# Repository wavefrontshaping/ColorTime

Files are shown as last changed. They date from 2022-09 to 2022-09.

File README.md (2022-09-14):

Color Time
==========
## *A passive-agressive tool to tell the speaker it is time to stop talking*

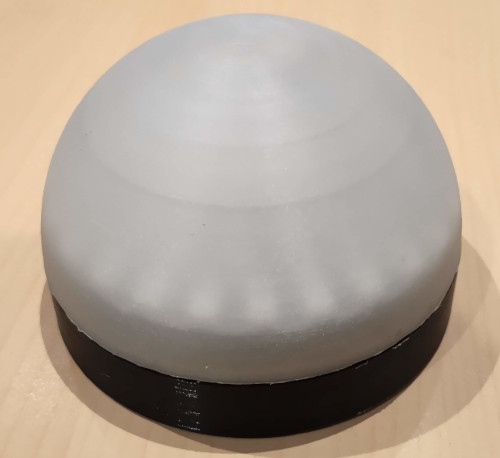
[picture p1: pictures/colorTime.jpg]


## Table of Content
1. [What is it?](#what)
2. [How does it work?](#how)
3. [Build it](#build)
4. [Usage](#usage)
5. [Credits](#credits)

## 1. What is it? 
During scientific talks it is sometimes difficult, or awkward, for the chairmen to warn speakers that they are exceeding their allotted time.
We developed a device, 
designed to be placed between the speaker and the audience, 
that indicates using a color coded light how much time they have left. 
It also signals the time for question and the end of the allotted time with color flashes.

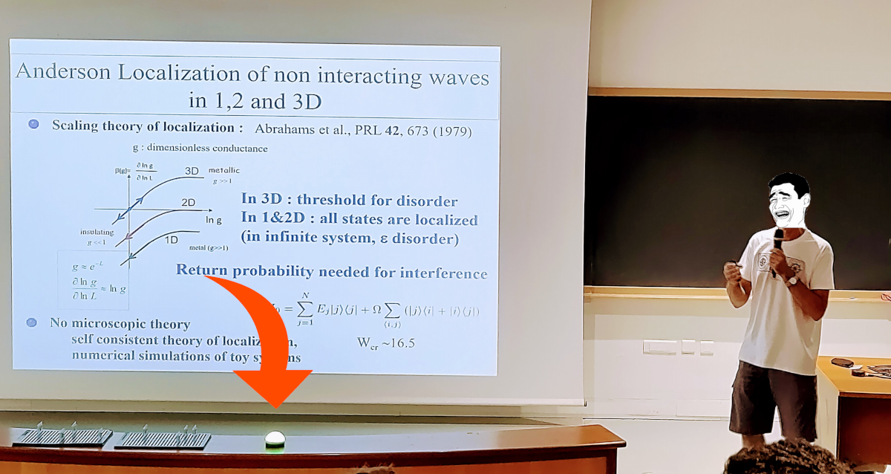
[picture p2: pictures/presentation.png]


## 2. How does it work? 

Once started and set up, the light of the device will gradually change from green to red during the time of the talk. 
It will also signal the time for questions with few red flashes and then will flash blue and red at the end of the talk to tell the speaker and chairman that the time is up. 

The device can be controlled using a push button by directly pressing on the device and/or using bluetooth with a smartphone.

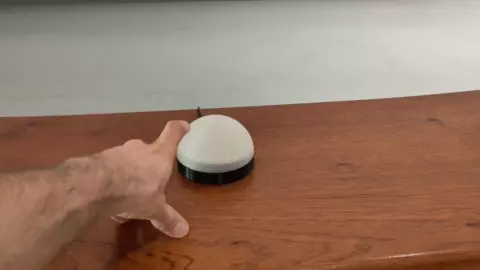
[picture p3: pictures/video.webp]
video


## 3. Build it 
### 3.1 Bill of materials
* 1x Raspberry Pi Pico
* 1. 6x6x4.5mm push button
* 1x 61-LED [[buy](https://www.amazon.fr/gp/product/B07L7ZPPV9/ref=ppx_yo_dt_b_asin_title_o00_s00?ie=UTF8&psc=1)] [[instructions](https://www.make-it.ca/ws2812-neopixel-ring-to-attiny85/)]
* 1x HC-05 (or HC-06) Bluetooth board [Optional]
* White and black (or colored) PLA for 3d printed parts

### 3.2 3d-printed parts

150 micron resolution is good enough. 
For the top part, use can use a translucent plastic but using white is good enough as light will still go through given the thickness of the shell.

### 3.3 Assembly

### 3.4 Button

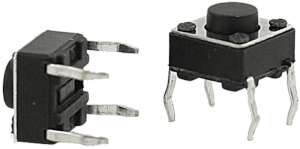
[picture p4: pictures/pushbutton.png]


Solder the two pins of the button, one to a `GND` pin of the board, the other to pin `GP9`.
Be careful to pass the wire through the hole before soldering them the the board.

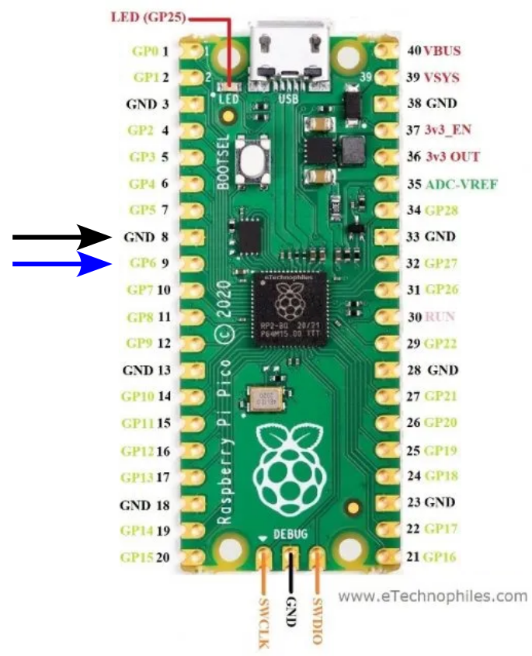
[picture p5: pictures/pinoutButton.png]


Then, push the button into the designated hole. 
Ideally, make it so the button sticks out a little bit. 
This way, you can press directly on the white dome to press the button. 

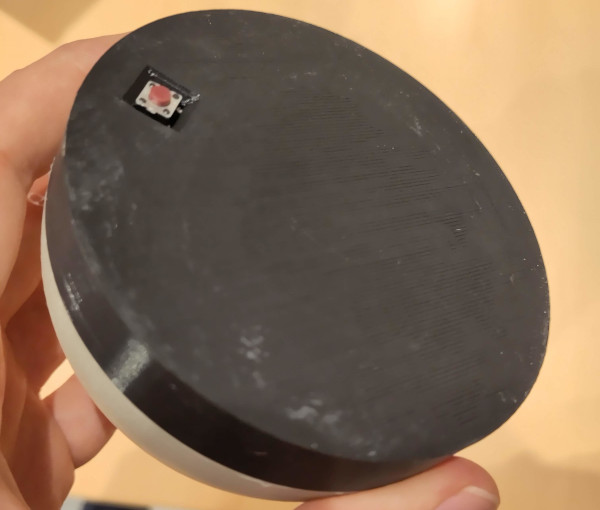
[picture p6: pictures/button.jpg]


### 3.5 LEDs
Simply follow the tutorial [here](https://www.make-it.ca/ws2812-neopixel-ring-to-attiny85/) for soldering the different rings. 
Then solder the `DI` digital input to `GP20`. Use `VBUS` (usb power) for `Vcc` and any `GND` pin for ground.

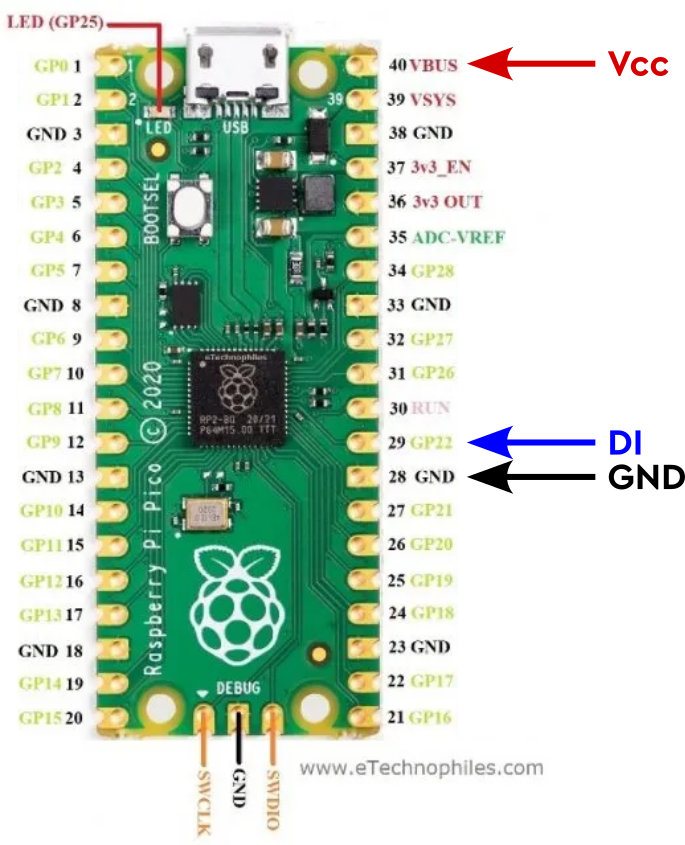
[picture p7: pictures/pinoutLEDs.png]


### 3.6 Blueooth [optional]

Once every thing soldered, place the Pico board so that the 
micro-usb socket is properly in place. 
You should be able to plug a power cord without moving the board.
You can keep the Pico in place with one drop of glue gun in the corners of the board.

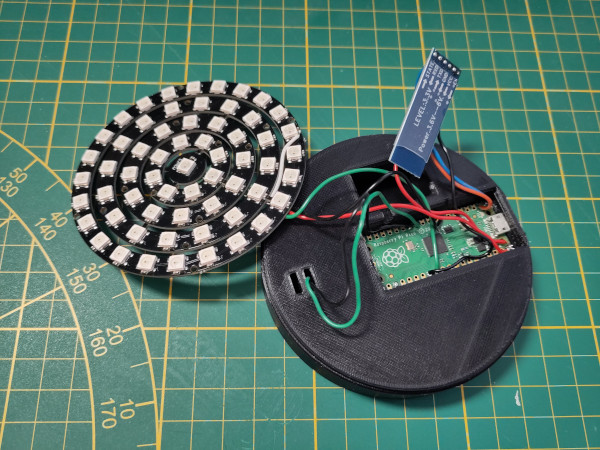
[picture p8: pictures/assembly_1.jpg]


Place a piece of paper (to prevent short circuit) on top of the Pico board and put the HC-05 on top of it.

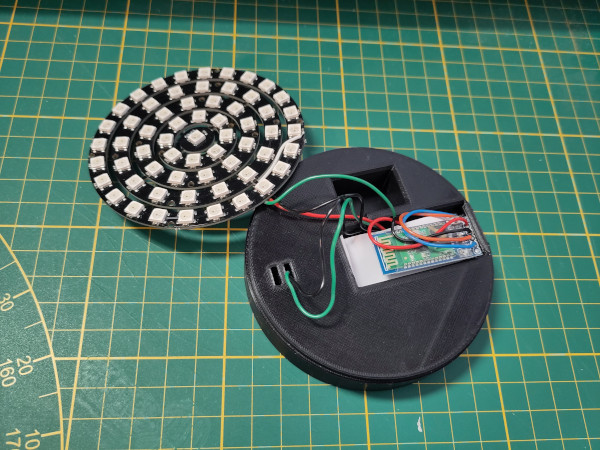
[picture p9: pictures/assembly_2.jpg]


### 3.7 Final assembly

Use a glue gun to keep the LEDs in place and final snap the top white dome onto the base. 
And you are done!

## 4. Usage

### 4.1 Preparation
If you intend to use the device without bluetooth, 
you need to set up few parameters in the code. 
However, you could make it work out of the box with just editing 
`state_time` to fit the duration of the talks.

* `state_time`: the list of different time for talks in minutes. 
  **Do not edit the first one** as it correspond to the demo of a duration of 20 seconds and for which the time for question is modified to be equal to 10 seconde, regardless of the value of `T_QUESTION`
* `state_colors`: list of colors for the different times. 
  Each color should be a list or tuple of three integers between 0 and 255. 
  This list should be of the same length as `state_time`
* `T_QUESTION`: time allotted for question. 
  The device will flash red for 4 seconds `T_QUESTION` minutes before the end of the talk.
* `BRIGHTNESS_MIN`: brightness at the beginning of the countdown.
* `BRIGHTNESS_MAX`:  brightness at the END of the countdown.
* `BRIGHTNESS_FLASH`: brightness for the flashes for the question signal and the end of the talk.
  
### 4.2 Power source

Plug the device to any power source using a micro-USB cable. 
A small power bank is typically enough for hours of usage.

### 4.3 Button commands

* `Single press`: switch to the next state (duration of talk) and start the count down.
* `Double press`: pause the countdown without stopping it. 
  `Single press` again to resume.
* `Long press`: stop the countdown and switch of the LEDs. 

### 4.4 Bluetooth communication

Communication is done using ASCII text message over a serial protocol. 

#### Commands
Commands are the following:
* `START`: start the countdown,
* `PAUSE`: pause the countdown, 
* `RESUME`: resume the countdown after pause,
* `STOP`: stop the countdown and switch of the LEDs
* `T{X}`: specify the time (in minutes) for a countdown and starts it, 
for instance `T20` sets a countdown for a 20-minute talk,
* `C{X}`: change the remaining time to `X` minutes.

#### Android phone

First enable Bluetooth on your smartphone and pair with the device. 
It should be called HC-05 (or HC-06) and the pin code is `0000` or `1234`. 

Then download and install [Serial Bluetooth Terminal](https://play.google.com/store/apps/details?id=de.kai_morich.serial_bluetooth_terminal). 
In the app, go to the `Devices` section the top left menu and select the HC-05 device. 
In the `Terminal` section, use the top left icon to initialize the connection.

You can now the serial terminal to send commands or use buttons. 
To configure a button, long press on it, give it a name and set the commands. This is how it looks like:

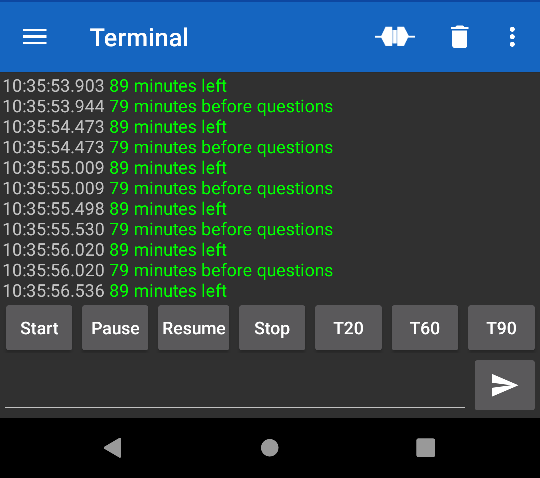
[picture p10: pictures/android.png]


Additionally, the device will send information about the time left before the questions and before the end of the talk.

## 5. Credits

* Idea: Fabrice Lemoult
* Design: Sébastien M. Popoff
* Tests: Sébastien M. Popoff, Romain Pierrat, and F. Lemoult

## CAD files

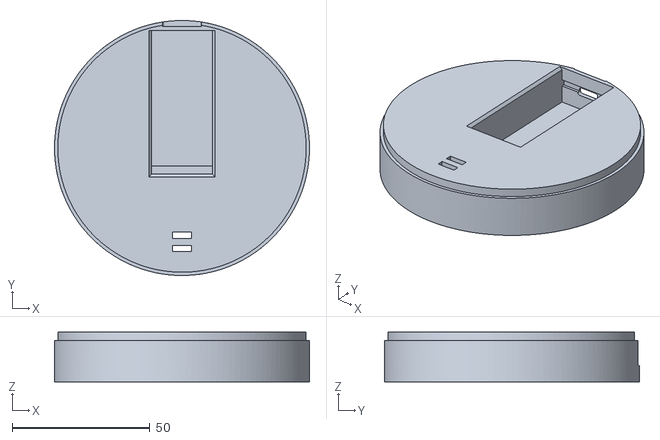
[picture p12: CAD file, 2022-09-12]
3d/bottom.stl
92.4 x 92.4 x 18.0

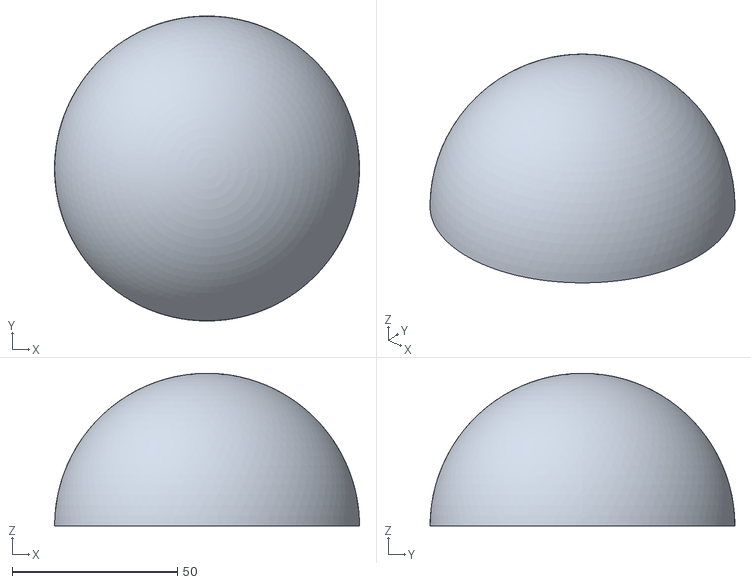
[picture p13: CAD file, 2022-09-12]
3d/top.stl
92.4 x 92.4 x 46.2

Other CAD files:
3d/colortime_3d.FCStd

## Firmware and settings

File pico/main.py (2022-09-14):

from machine import Pin, UART
from primitives.pushbutton import Pushbutton
import uasyncio as asyncio
import _thread
from utime import ticks_ms, sleep_ms
from ledDisk import LedDisk, RED

light_blue = (0,0,127)
light_orange = (100,50,0)
light_green = (0,127,0)
light_red = (127,0,0)

state_time = [0.33,90,60,20] # in minutes
state_colors = (light_green, light_blue, light_orange, light_red)
nb_states = len(state_time)
tick_time = 1. #seconds

# Configure led disk
led_pin = 22
leds = LedDisk(led_pin)
leds.Off()
# leds.rotate(2000)
# leds.wave(4000)

# Bluetooth serial connexion
uart = UART(0,9600)


# Global variables
state = 0
t0 = 0
tmax = state_time[state]*60*1000
time = 0.

# Signals if the countdown has started yet
FLAG_START = False
# Signals when to stop the countdown
FLAG_STOPPED = True
# Signal when to start the coundown
FLAG_QUESTION = False

BRIGHTNESS_MAX = .2
BRIGHTNESS_MIN = .2
BRIGHTNESS_FLASH = .4

T_QUESTION = 10*60*1000#10*60*1000
T_FLASH = 1*60*1000


btn_pin = Pin(9, Pin.IN, pull=Pin.PULL_UP)  # Pushbutton



    
async def switch_state():
    global state
    state += 1
    state = state%nb_states
    leds.Blink(state_colors[state], timeout = 1000)
    print('Changing state to:', state)
    start()

def single_press():
    print('Single press')
    if FLAG_START:
        print('flag', FLAG_START)
        print('Start')
        await switch_state()
    if FLAG_STOPPED:
        start()
    resume()

def long_press():
    print("Long press")
    stop()

def resume():
    global FLAG_START
    FLAG_START = True
    
def start():
    global t0, tmax
    t0 = ticks_ms()
    tmax = state_time[state]*60*1000
    print(f'Total time: {state_time[state]} minutes')
    
def stop():
    global FLAG_START, FLAG_STOPPED
    FLAG_START = False
    FLAG_STOPPED = True
    leds.Off()
    
def pause():
    global FLAG_START
    FLAG_START = False
    
def double_press():
    print('Double press')
    pause()

def get_bt_message(data):
    global FLAG_START, FLAG_QUESTION
    global t0, tmax, state
    msg = ''.join([chr(b) for b in data])
    msg = msg.strip()
    print('Message: ', msg)
    if msg[0] == 'T':
        try:
            tmax = int(msg[1:])*60*1000
            state = 1 #not demo!
            print('New time:', tmax, msg[1:])
            FLAG_START = True
            FLAG_QUESTION = False
            t0 = ticks_ms()
        except:
            pass
    if msg[0] == 'C':
        try:
            # change time left
            time_left = int(msg[1:])*60*1000
            shift = tmax-ticks_ms()+t0-time_left
            t0 -= shift
        except:
            pass
    elif msg == 'START':
        print('Start/Restart')
        start()
        resume()
    elif msg == 'PAUSE':
        print('Pausing')
        pause()
    elif msg == 'RESUME':
        print('Resuming')
        resume()
    elif msg == 'STOP':
        print('Stopping')
        stop()
    elif msg == 'SWITCH':
        print('Switching')
        switch_state()
        resume()
        
    
def bt_thread(uart):
    global blue_btn   
    while True:
        if uart.any():
            print('/BT')
            data = uart.read(32)
            get_bt_message(data)
            print('BT/')
            
_thread.start_new_thread(bt_thread, (uart,))

def DisplayTimeLeft(time, tmax, tquestion):
    seconds_left = (tmax-time)/1_000
    minutes_left = seconds_left/60
    if minutes_left > 1.:
        message = f'{int(minutes_left)} minutes left\n'
    elif minutes_left > 0:
        message = f'{int(seconds_left)} seconds left\n'
    
    seconds_before_questions = (tquestion-time)/1_000
    minutes_before_questions = seconds_before_questions/60
    if minutes_before_questions > 1:
        message += f'{int(minutes_before_questions)} minutes before questions\n'
    elif seconds_before_questions > 0:
        message += f'{int(seconds_before_questions)} seconds before questions\n'
    uart.write(message)
    print(message)

async def main():
    global FLAG_QUESTION, t0, time
    pb = Pushbutton(btn_pin, suppress = True)
    pb.release_func(single_press, ())  # Callback on button press
    pb.double_func(double_press, ())
    pb.long_func(long_press, ())  # Callback on long press
    t0 = ticks_ms()
    while True:
        await asyncio.sleep(tick_time)            
        if FLAG_START:
            time = ticks_ms()-t0            
            t_question = T_QUESTION if state > 0 else 10*1000
            if time>tmax-t_question:
                if not FLAG_QUESTION:
                    leds.Blink(RED, timeout = 4_000, brightness = BRIGHTNESS_FLASH)
                    FLAG_QUESTION = True
                leds.Step(1., BRIGHTNESS_MIN, BRIGHTNESS_MAX)
            leds.Step(time/(tmax-t_question), BRIGHTNESS_MIN, BRIGHTNESS_MAX)
            if time > tmax:
                print('Stop')
                leds.Flash(timeout = T_FLASH, brightness = BRIGHTNESS_FLASH)
                stop()
            else:
                DisplayTimeLeft(time, tmax, tmax-t_question)
        else:
            # continue adding time to t0 to resume where we stopped
            t0 = ticks_ms()-time
            print('Pause block', t0, FLAG_START)
            
try:
    asyncio.run(main())
finally:
    asyncio.new_event_loop()

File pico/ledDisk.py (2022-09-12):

from neopixel import Neopixel
from utime import ticks_ms, sleep_ms

N_LEDS = 61

RED = (255,0,0)
BLUE = (0,0,255)
GREEN = (0,255,0)
BLACK = (0,0,0)
ORANGE = (255, 165, 0)
YELLOW = (255, 255, 0)
WHITE = (255,255,255)

RGB_COLORS = [[0, 128, 0], [1, 128, 0], [2, 129, 0], [3, 129, 0], [5, 130, 0], [6, 131, 0], [7, 131, 0], [9, 132, 0], [10, 133, 0], [12, 133, 0], [13, 134, 0], [14, 135, 0], [16, 135, 0], [17, 136, 0], [19, 136, 0], [20, 137, 0], [22, 138, 0], [23, 138, 0], [25, 139, 0], [26, 140, 0], [28, 140, 0], [29, 141, 0], [31, 142, 0], [32, 142, 0], [34, 143, 0], [36, 143, 0], [37, 144, 0], [39, 145, 0], [41, 145, 0], [42, 146, 0], [44, 147, 0], [46, 147, 0], [47, 148, 0], [49, 149, 0], [51, 149, 0], [52, 150, 0], [54, 150, 0], [56, 151, 0], [58, 152, 0], [59, 152, 0], [61, 153, 0], [63, 154, 0], [65, 154, 0], [67, 155, 0], [69, 156, 0], [70, 156, 0], [72, 157, 0], [74, 157, 0], [76, 158, 0], [78, 159, 0], [80, 159, 0], [82, 160, 0], [84, 161, 0], [86, 161, 0], [88, 162, 0], [90, 163, 0], [92, 163, 0], [94, 164, 0], [96, 165, 0], [98, 165, 0], [100, 166, 0], [102, 166, 0], [104, 167, 0], [106, 168, 0], [108, 168, 0], [110, 169, 0], [112, 170, 0], [114, 170, 0], [117, 171, 0], [119, 172, 0], [121, 172, 0], [123, 173, 0], [125, 173, 0], [128, 174, 0], [130, 175, 0], [132, 175, 0], [134, 176, 0], [137, 177, 0], [139, 177, 0], [141, 178, 0], [143, 179, 0], [146, 179, 0], [148, 180, 0], [150, 180, 0], [153, 181, 0], [155, 182, 0], [158, 182, 0], [160, 183, 0], [162, 184, 0], [165, 184, 0], [167, 185, 0], [170, 186, 0], [172, 186, 0], [175, 187, 0], [177, 187, 0], [180, 188, 0], [182, 189, 0], [185, 189, 0], [187, 190, 0], [190, 191, 0], [191, 190, 0], [192, 189, 0], [193, 188, 0], [193, 186, 0], [194, 185, 0], [195, 184, 0], [195, 182, 0], [196, 181, 0], [196, 180, 0], [197, 178, 0], [198, 177, 0], [198, 175, 0], [199, 174, 0], [200, 172, 0], [200, 171, 0], [201, 170, 0], [202, 168, 0], [202, 167, 0], [203, 165, 0], [203, 163, 0], [204, 162, 0], [205, 160, 0], [205, 159, 0], [206, 157, 0], [207, 156, 0], [207, 154, 0], [208, 152, 0], [209, 151, 0], [209, 149, 0], [210, 147, 0], [210, 146, 0], [211, 144, 0], [212, 142, 0], [212, 141, 0], [213, 139, 0], [214, 137, 0], [214, 136, 0], [215, 134, 0], [216, 132, 0], [216, 130, 0], [217, 128, 0], [217, 127, 0], [218, 125, 0], [219, 123, 0], [219, 121, 0], [220, 119, 0], [221, 117, 0], [221, 115, 0], [222, 114, 0], [223, 112, 0], [223, 110, 0], [224, 108, 0], [225, 106, 0], [225, 104, 0], [226, 102, 0], [226, 100, 0], [227, 98, 0], [228, 96, 0], [228, 94, 0], [229, 92, 0], [230, 90, 0], [230, 88, 0], [231, 86, 0], [232, 83, 0], [232, 81, 0], [233, 79, 0], [233, 77, 0], [234, 75, 0], [235, 73, 0], [235, 71, 0], [236, 68, 0], [237, 66, 0], [237, 64, 0], [238, 62, 0], [239, 60, 0], [239, 57, 0], [240, 55, 0], [240, 53, 0], [241, 50, 0], [242, 48, 0], [242, 46, 0], [243, 44, 0], [244, 41, 0], [244, 39, 0], [245, 36, 0], [246, 34, 0], [246, 32, 0], [247, 29, 0], [247, 27, 0], [248, 24, 0], [249, 22, 0], [249, 20, 0], [250, 17, 0], [251, 15, 0], [251, 12, 0], [252, 10, 0], [253, 7, 0], [253, 5, 0], [254, 2, 0], [255, 0, 0]]

N_STEPS = len(RGB_COLORS)

PARTS = [[0,1,2,3,24,25,26,40,41,52],
         [4,5,6,7,27,28,42,43,53,54],
         [8,9,10,29,30,31,44,45,55],
         [11,12,13,14,32,33,46,47,56],
         [15,16,17,34,35,36,48,57],
         [18,19,20,36,37,49,50,58],
         [21,22,23,38,39,51,59,60]]

N_PARTS = len(PARTS)

def _apply_brightness(color, brightness):
    return [min(int(x*brightness),x) for x in color]

class LedDisk():

    def __init__(self, pin):
        self.leds = Neopixel(N_LEDS, 0, pin, "GRB")

    def Rotate(self, timeout = 60_000, stop_callback = None):
        t0 = ticks_ms()
        ind_blue = [0,1,2]
        while True:
            for i_r in range(N_PARTS):
                ind_parts = [(x+i_r)%N_PARTS for x in ind_blue]           
                all_blue = []
                for i_blue in ind_parts:
                    all_blue += PARTS[i_blue]
                for i in range(N_LEDS):
                    if i in all_blue:
                        self.leds.set_pixel(i, BLUE)
                    else:
                        self.leds.set_pixel(i, RED)
                self.leds.show()
                sleep_ms(25)
            if stop_callback and stop_callback():
                return
            if(ticks_ms()-t0 > timeout):
                return

    def Wave(
        self,
        timeout = 60_000,
        stop_callback = None,
        pause = 50
    ):
        def check_stop():
            if stop_callback and stop_callback():
                return True
            if(ticks_ms()-t0 > timeout):
                return True
            return False
        t0 = ticks_ms()
        while True:
            for i in range(N_LEDS):
                self.leds.set_pixel(i, BLUE)
                self.leds.show()
                sleep_ms(pause)
                if check_stop():
                    return
            for i in range(N_LEDS):
                self.leds.set_pixel(i, RED)
                self.leds.show()
                sleep_ms(pause)
                if check_stop():
                    return

    def Blink(
        self,
        color = RED,
        timeout = 60_000,
        stop_callback = None,
        pause = 150,
        brightness = 1.,
    ):
        self.Flash(
            color1 = color,
            color2 = BLACK,
            timeout = timeout,
            stop_callback = stop_callback,
            pause = pause,
            brightness = brightness
        )

    def Flash(
        self,
        color1 = RED,
        color2 = BLUE,
        timeout = 60_000,
        stop_callback = None,
        pause = 150,
        brightness = 1.,
    ):
        t0 = ticks_ms()
        while True:
            self.leds.fill(_apply_brightness(color1, brightness))
            self.leds.show()
            sleep_ms(pause)
            self.leds.fill(_apply_brightness(color2, brightness))
            self.leds.show()
            sleep_ms(pause)
            if stop_callback and stop_callback():
                return
            if(ticks_ms()-t0 > timeout):
                return

    def Step(self, step_value, brightness_min = 1., brightness_max = 1.):

        if brightness_min == brightness_max:
            brightness = brightness_max
        else:
            brightness = min(step_value*(brightness_max-brightness_min)+brightness_min,1.)
        i_step = min(int(step_value*N_STEPS), N_STEPS-1)
        new_color = _apply_brightness(RGB_COLORS[i_step], brightness)
        self.leds.fill(new_color)
        self.leds.show()

    def Red(self):
        self.leds.fill(RED)
        self.leds.show()

    def Green(self):
        self.leds.fill(GREEN)
        self.leds.show()

    def Blue(self):
        self.leds.fill(BLUE)
        self.leds.show()

    def Off(self):
        self.leds.fill(BLACK)
        self.leds.show()

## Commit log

2022-09-12 correct bug with question
    [main.py]
2022-09-12 remove hole for sound board
    [bottom.stl, colortime_3d_sound.FCStd]
2022-09-14 correct command to set time left
    [main.py]
